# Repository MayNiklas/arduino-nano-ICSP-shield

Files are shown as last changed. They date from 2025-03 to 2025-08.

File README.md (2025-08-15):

# arduino-nano-ICSP-shield

A simple shield, that exposes a 6 pin ICSP header to use an Arduino Nano as a ISP programmer.

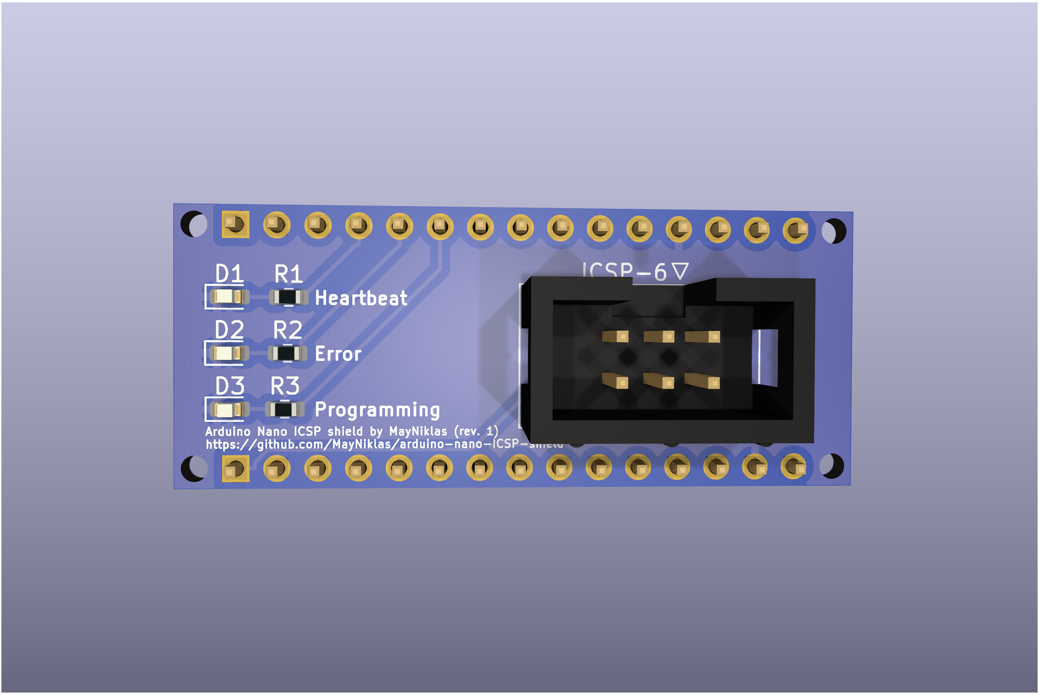
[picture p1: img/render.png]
3D render of the PCB, fully populated


## BOM

Interactive BOM available: https://mayniklas.github.io/arduino-nano-ICSP-shield/

I'm linking the products I'm testing with, not the ones I recommend.

* 1x [Arduino Nano](https://www.aliexpress.com/item/1005007392605300.html?spm=a2g0o.order_list.order_list_main.17.49c7180237FQjT)
* 1x [6 pin 2x3 IDC3 Box Headers](https://www.aliexpress.com/item/1005007470581902.html)
* 1x [6 pin 2x3 Pitch JTAG ISP Ribbon Cable](https://www.aliexpress.com/item/1005004762590129.html)
* 1x [0603 SMD - 10µF electrolytic capacitor](https://www.lcsc.com/product-detail/Multilayer-Ceramic-Capacitors-MLCC-SMD-SMT_Samsung-Electro-Mechanics-CL10A106KP8NNNC_C19702.html)
* 3x [0603 SMD - LED](https://www.lcsc.com/product-detail/LED-Indication-Discrete_XINGLIGHT-XL-1608SURC-06_C965799.html)
* 3x [0603 SMD - 470 Ohm Resistor](https://www.lcsc.com/product-detail/Chip-Resistor-Surface-Mount_UNI-ROYAL-Uniroyal-Elec-0603WAF4700T5E_C23179.html)

## Documentation

* [Arduino as ISP](https://docs.arduino.cc/built-in-examples/arduino-isp/ArduinoISP/)

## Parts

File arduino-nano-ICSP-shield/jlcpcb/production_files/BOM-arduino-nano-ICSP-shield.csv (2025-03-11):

Comment | Designator | Footprint | LCSC | Quantity
10µF | C1 | C_0603_1608Metric | C19702 | 1
470 | R1,R2,R3 | R_0603_1608Metric | C23179 | 3
LED | D1,D2,D3 | LED_0603_1608Metric | C965799 | 3
AVR-ISP-6 | J3 | IDC-Header_2x03_P2.54mm_Vertical-ICSP-6 |  | 1
Analog | J1 | PinHeader_1x15_P2.54mm_Vertical |  | 1
Digital | J2 | PinHeader_1x15_P2.54mm_Vertical |  | 1

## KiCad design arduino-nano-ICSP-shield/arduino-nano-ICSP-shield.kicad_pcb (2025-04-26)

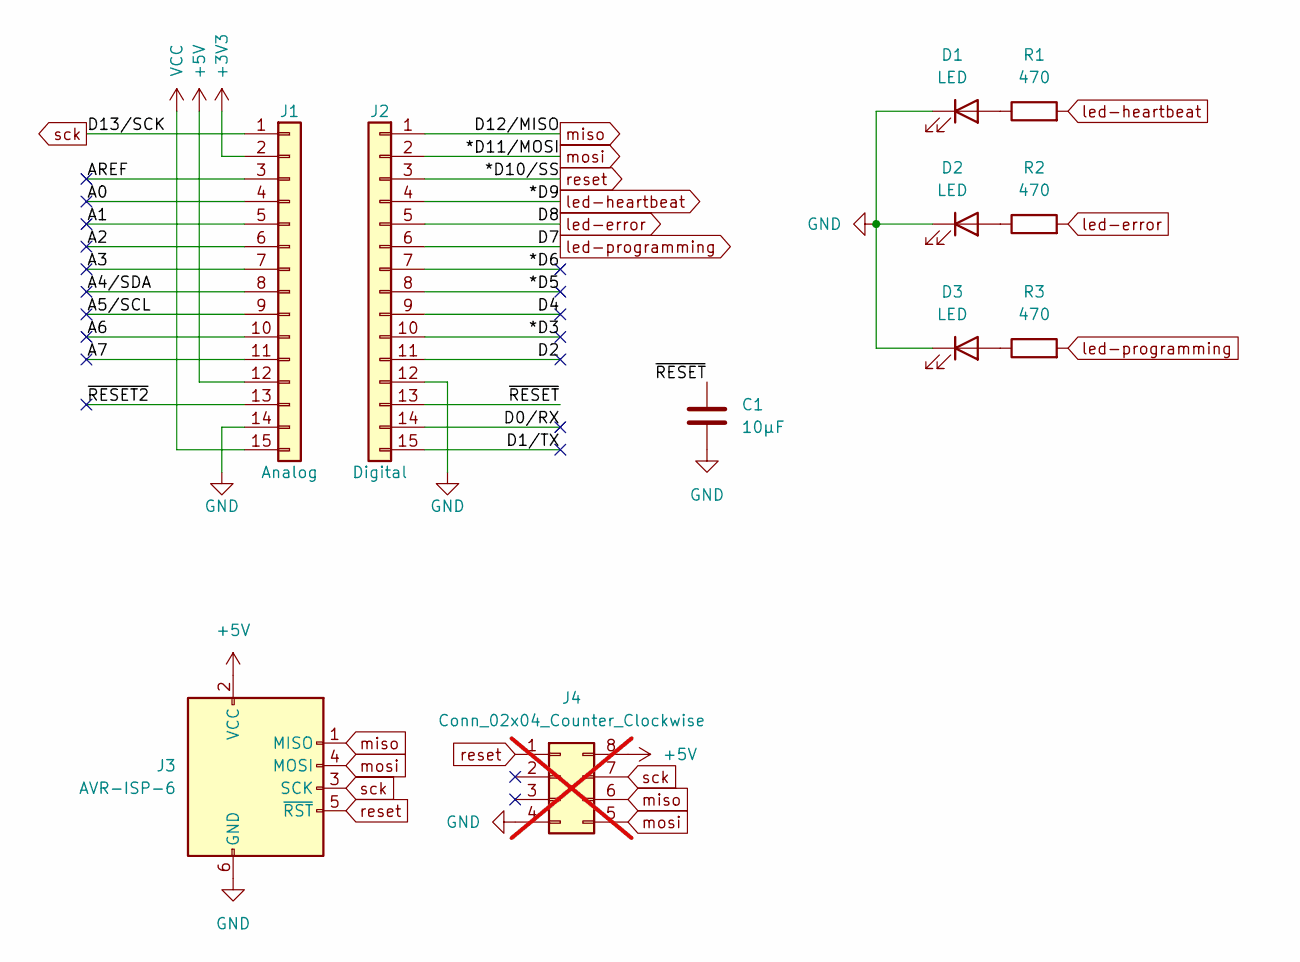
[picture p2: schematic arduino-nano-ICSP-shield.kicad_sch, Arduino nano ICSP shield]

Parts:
C1: 10µF; C_0603_1608Metric; LCSC C19702
D1, D2, D3: LED; LED_0603_1608Metric; LCSC C965799
J1: Analog; PinHeader_1x15_P2.54mm_Vertical
J2: Digital; PinHeader_1x15_P2.54mm_Vertical
J3: AVR-ISP-6; IDC-Header_2x03_P2.54mm_Vertical-ICSP-6; LCSC C7430309
J4: Conn_02x04_Counter_Clockwise; PinHeader_2x04_P2.54mm_Vertical_Counterclockwise-Clip; not fitted
R1, R2, R3: 470; R_0603_1608Metric; LCSC C23179

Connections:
+3V3: J1.2
+5V: J1.12, J3.2 (VCC), J4.8
/*D3: J2.10
/*D5: J2.8
/*D6: J2.7
/A0: J1.4
/A1: J1.5
/A2: J1.6
/A3: J1.7
/A4/SDA: J1.8
/A5/SCL: J1.9
/A6: J1.10
/A7: J1.11
/AREF: J1.3
/D0/RX: J2.14
/D1/TX: J2.15
/D2: J2.11
/D4: J2.9
/~RESET2: J1.13
/~RESET: C1.1, J2.13
GND: C1.2, D1.1 (K), D2.1 (K), D3.1 (K), J1.14, J2.12, J3.6 (GND), J4.4
unnamed: D1.2 (A), R1.1
unnamed: D2.2 (A), R2.1
unnamed: D3.2 (A), R3.1
VCC: J1.15
led-error: J2.5, R2.2
led-heartbeat: J2.4, R1.2
led-programming: J2.6, R3.2
miso: J2.1, J3.1 (MISO), J4.6
mosi: J2.2, J3.4 (MOSI), J4.5
reset: J2.3, J3.5 (~RST), J4.1
sck: J1.1, J3.3 (SCK), J4.7

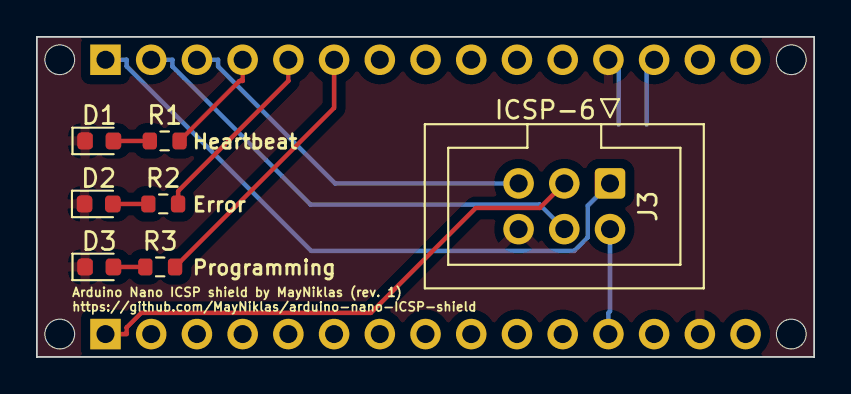
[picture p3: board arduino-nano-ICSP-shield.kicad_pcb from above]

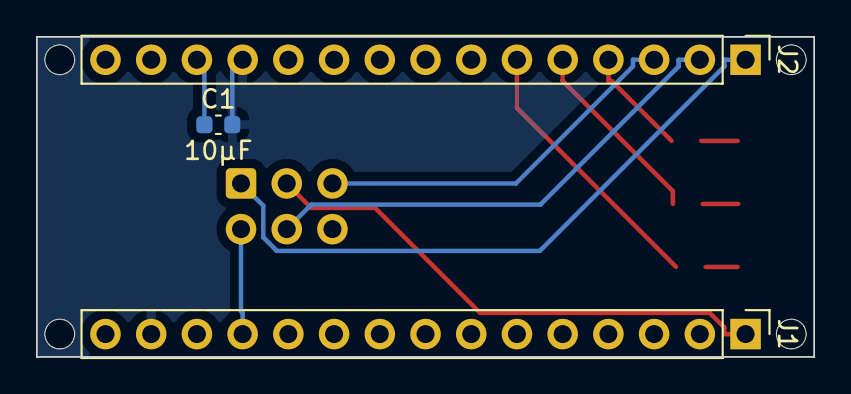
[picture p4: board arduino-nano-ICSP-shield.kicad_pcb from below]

Board: 2 copper layers, 43.2 x 17.8 mm, 14 parts (3 on the bottom side), 13 nets.

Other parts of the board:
MH1, MH2, MH3, MH4: MountingHole_65mil

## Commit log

2025-03-07 init led's
    [arduino-nano-ICSP-shield.kicad_pcb, arduino-nano-ICSP-shield.kicad_sch]
2025-03-08 add ports
    [arduino-nano-ICSP-shield.kicad_pcb, arduino-nano-ICSP-shield.kicad_sch]
2025-03-08 single header
    [arduino-nano-ICSP-shield.kicad_pcb, arduino-nano-ICSP-shield.kicad_sch]
2025-03-08 print 10µF
    [arduino-nano-ICSP-shield.kicad_pcb]
2025-03-09 move parts to the back
    [arduino-nano-ICSP-shield.kicad_pcb]
2025-03-09 add jlcpcb folder
    [BOM-arduino-nano-ICSP-shield.csv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]
2025-03-09 remove linked pins & route
    [arduino-nano-ICSP-shield.kicad_pcb, arduino-nano-ICSP-shield.kicad_sch]
2025-03-09 add 140 Ohm resistor to the components list and remove 150 Ohm resistor
2025-03-09 flip resistor
    [arduino-nano-ICSP-shield.kicad_pcb, arduino-nano-ICSP-shield.kicad_sch]
2025-03-09 routed by hand
    [arduino-nano-ICSP-shield.kicad_pcb, arduino-nano-ICSP-shield.kicad_sch]
2025-03-09 add no_connect
    [arduino-nano-ICSP-shield.kicad_sch]
2025-03-09 3 different resistors
    [arduino-nano-ICSP-shield.kicad_sch]
2025-03-09 Readd Clip
    [arduino-nano-ICSP-shield.kicad_pcb, arduino-nano-ICSP-shield.kicad_sch]
2025-03-10 split RESET into RESET & RESET2
    [arduino-nano-ICSP-shield.kicad_pcb, arduino-nano-ICSP-shield.kicad_sch]
2025-03-10 add ttle
    [arduino-nano-ICSP-shield.kicad_sch]
2025-03-10 add text
    [arduino-nano-ICSP-shield.kicad_pcb]
2025-03-10 move text down
    [arduino-nano-ICSP-shield.kicad_pcb]
2025-03-10 add led- to label name
    [arduino-nano-ICSP-shield.kicad_pcb, arduino-nano-ICSP-shield.kicad_sch]
2025-03-10 change color
    [arduino-nano-ICSP-shield.kicad_pcb]
2025-03-10 move condensator
    [arduino-nano-ICSP-shield.kicad_pcb, arduino-nano-ICSP-shield.kicad_sch]
2025-03-10 set lcsc id's
    [arduino-nano-ICSP-shield.kicad_pcb]
2025-03-11 export project
    [BOM-arduino-nano-ICSP-shield.csv, arduino-nano-ICSP-shield.kicad_pcb, arduino-nano-ICSP-shield.kicad_sch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]
2025-03-11 create ibom
    [arduino-nano-ICSP-shield.kicad_pcb, arduino-nano-ICSP-shield.kicad_sch]
2025-04-26 add LCSC property to schematic
    [arduino-nano-ICSP-shield.kicad_pcb, arduino-nano-ICSP-shield.kicad_sch]
2025-04-26 changes caused by updates in KiCad
    [arduino-nano-ICSP-shield.kicad_pcb]
2025-04-26 switch to using KiBot
2025-04-26 add LCSC # for 10uF
    [arduino-nano-ICSP-shield.kicad_pcb]
2025-08-15 add definitions for footprint values in KiBot configuration
